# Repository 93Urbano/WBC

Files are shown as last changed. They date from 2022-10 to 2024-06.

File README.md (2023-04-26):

# WBC
WiFi-Bluetooth CAN-UART Datalogger ESP32
Currenly Desings:
- WBC_02 -> Wifi-Bluetooth-CAN board
  
- WBCR_02 -> Wifi-Bluetooth-CAN and Relays board

  


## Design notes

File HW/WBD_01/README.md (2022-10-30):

# WBC
WiFi-Bluetooth CAN-UART Datalogger ESP32

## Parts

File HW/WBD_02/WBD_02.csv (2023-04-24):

Qty | Value | Device | Package | Parts | Description | ARROW_PART_NUMBER | ARROW_PRICE-STOCK | DESCRIPTION | HEIGHT | MANUFACTURER_NAME | MANUFACTURER_PART_NUMBER | MOUSER_PART_NUMBER | MOUSER_PRICE-STOCK | MOUSER_TESTING_PART_NUMBER | MOUSER_TESTING_PRICE-STOCK | POPULARITY | SPICEPREFIX
2 |  | PINHD-1X2 | 1X02 | CAN, VBAT | PIN HEADER |  |  |  |  |  |  |  |  |  |  | 98
1 |  | PINHD-1X6 | 1X06 | UART/I2C | PIN HEADER |  |  |  |  |  |  |  |  |  |  | 79
6 | 0.1uF | C-EUC0603 | C0603 | C2, C3, C8, C9, C10, C11 | CAPACITOR, European symbol
1 | 100nF | C-EUC0603 | C0603 | C5 | CAPACITOR, European symbol
1 | 10k | R-EU_R0603 | R0603 | R1 | RESISTOR, European symbol |  |  |  |  |  |  |  |  |  |  | 70 | R
1 | 10uF | C-EUC0603 | C0603 | C6 | CAPACITOR, European symbol
1 | 13k | R-EU_R0603 | R0603 | R3 | RESISTOR, European symbol |  |  |  |  |  |  |  |  |  |  | 70 | R
3 | 150060GS75000 | 150060GS75000 | LEDC1608X80N | 3V3, LED, VIN | Wurth Elektronik WL-SMCW 520 nm Green LED, 1608 (0603) Clear SMD package |  |  | Wurth Elektronik WL-SMCW 520 nm Green LED, 1608 (0603) Clear SMD package | 0.8mm | Wurth Elektronik | 150060GS75000 | 710-150060GS75000 | https://www.mouser.co.uk/ProductDetail/Wurth-Elektronik/150060GS75000?qs=LlUlMxKIyB0UYkq5lDO8nA%3D%3D
1 | 1k | R-EU_R0603 | R0603 | R9 | RESISTOR, European symbol |  |  |  |  |  |  |  |  |  |  | 70 | R
1 | 20uF | C-EUC0603 | C0603 | C1 | CAPACITOR, European symbol
1 | 216990-0003 | 216990-0003 | 2169900003 | USBC | USB Connectors Mid-Mnt SMT CH0.58 16Ckt Type C Rec. |  |  | USB Connectors Mid-Mnt SMT CH0.58 16Ckt Type C Rec. | 3.36mm | Molex | 216990-0003 | 538-216990-0003 | https://www.mouser.co.uk/ProductDetail/Molex/216990-0003?qs=DRkmTr78QASn0GILUGAYCA%3D%3D
1 | 22pF | C-EUC0603 | C0603 | C4 | CAPACITOR, European symbol
1 | 22uF | C-EUC0603 | C0603 | C7 | CAPACITOR, European symbol
1 | 2k2 | R-EU_R0603 | R0603 | R8 | RESISTOR, European symbol |  |  |  |  |  |  |  |  |  |  | 70 | R
3 | 330 | R-EU_R0603 | R0603 | R4, R5, R10 | RESISTOR, European symbol |  |  |  |  |  |  |  |  |  |  | 70 | R
1 | 4.7uH | L-EUL5650M | L5650M | L1 | INDUCTOR, European symbol |  |  |  |  |  |  |  |  |  |  | 0 | L
1 | 40.2k | R-EU_R0603 | R0603 | R2 | RESISTOR, European symbol |  |  |  |  |  |  |  |  |  |  | 70 | R
2 | 5.1k | R-EU_R0603 | R0603 | R6, R7 | RESISTOR, European symbol |  |  |  |  |  |  |  |  |  |  | 70 | R
1 | 5V5 1F | DB-5R5D105T | CAPPRD500W130D2150H800 | SUPERCAPACITOR | Supercapacitors / Ultracapacitors MEM CAP 5.5V 1.0F |  |  | Supercapacitors / Ultracapacitors MEM CAP 5.5V 1.0F | 8mm | Elna | DB-5R5D105T | 555-DB-5R5D105T | https://www.mouser.co.uk/ProductDetail/Elna/DB-5R5D105T?qs=r8OyiFxb6Rcu1BWmqcONIQ%3D%3D
1 | AT24C32D-SSHM-B | AT24C32D-SSHM-B | SOIC127P600X175-8N | IC5 | AT24C32D-SSHM-B, EEPROM Memory 32kbit,, 4096 x, 8bit, Serial-2 Wire, 550ns 1.7 5.5 V, 8-Pin SOIC |  |  | AT24C32D-SSHM-B, EEPROM Memory 32kbit,, 4096 x, 8bit, Serial-2 Wire, 550ns 1.7 5.5 V, 8-Pin SOIC | 1.75mm | Microchip | AT24C32D-SSHM-B | 556-AT24C32D-SSHM-B | https://www.mouser.co.uk/ProductDetail/Microchip-Technology-Atmel/AT24C32D-SSHM-B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
1 | BAS85,115 | BAS85,115 | BAS85115 | D2 | Schottky Diodes & Rectifiers SCHOTTKY 30V 200MA |  |  | Schottky Diodes & Rectifiers SCHOTTKY 30V 200MA | 1.6mm | Nexperia | BAS85,115 | 771-BAS85-T/R | https://www.mouser.co.uk/ProductDetail/Nexperia/BAS85115?qs=me8TqzrmIYWCmVXtgUH2Gg%3D%3D
1 | DIO6970TST6 | DIO6970TST6 | SOT95P280X90-6N | IC2 | Switching Voltage Regulators 2A Step Converter 24V Input Sync |  |  | Switching Voltage Regulators 2A Step Converter 24V Input Sync | 0.9mm | DIOO Microcircuits | DIO6970TST6 | 453-DIO6970ST6 | https://www.mouser.co.uk/ProductDetail/DIOO-Microcircuits/DIO6970TST6?qs=%252BEew9%252B0nqrCWpKu8WqElxA%3D%3D
1 | DS05-127-2-04BK-SMT-TR | DS05-127-2-04BK-SMT-TR | DS05127204BKSMTTR | IC7 | DIP Switches / SIP Switches DIP Switch, SPST, 1.27 pitch, flat actuator, SMT, Tape and reel, 4 position, Black |  |  | DIP Switches / SIP Switches DIP Switch, SPST, 1.27 pitch, flat actuator, SMT, Tape and reel, 4 position, Black | 2.6mm | CUI Devices | DS05-127-2-04BK-SMT-TR | 490-DS05127204BK-STR | https://www.mouser.co.uk/ProductDetail/CUI-Devices/DS05-127-2-04BK-SMT-TR?qs=wnTfsH77Xs6LBykqEPH3sg%3D%3D
1 | DS3231M+TRL | DS3231M+TRL | SOIC127P1032X265-16N | IC4 | +/-5ppm, I2C Real-Time Clock |  |  | +/-5ppm, I2C Real-Time Clock | 2.65mm | Maxim Integrated | DS3231M+TRL | 700-DS3231M+TRL | https://www.mouser.co.uk/ProductDetail/Maxim-Integrated/DS3231M%2bTRL?qs=Bakm8ERcljq5PBzSwLfmgg%3D%3D
1 | ESP32-S3-WROOM-1-N16 | ESP32-S3-WROOM-1-N16 | ESP32S3WROOM1N16 | ESP32 | WiFi Modules - 802.11 [Engineering Samples] SMD Module, ESP32-S3, 16 MB SPI Flash, PCB Antenna |  |  | WiFi Modules - 802.11 [Engineering Samples] SMD Module, ESP32-S3, 16 MB SPI Flash, PCB Antenna | 3.25mm | Espressif Systems | ESP32-S3-WROOM-1-N16 | 356-ESP32S3WROOM1N16 | https://www.mouser.co.uk/ProductDetail/Espressif-Systems/ESP32-S3-WROOM-1-N16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
1 | MICROSD-PUSH-OUT | MICROSD-PUSH-OUT | MICROSD-PUSH-OUT | MICROSD | T-Flash Push-Out Micro SD Card Reader
1 | SN65HVD232D | SN65HVD232D | SOIC127P600X175-8N | IC3 | CAN Transceiver 1Mbit/s ISO 11898, 8-Pin SOIC |  |  | CAN Transceiver 1Mbit/s ISO 11898, 8-Pin SOIC | 1.75mm | Texas Instruments | SN65HVD232D | 595-SN65HVD232D | https://www.mouser.co.uk/ProductDetail/Texas-Instruments/SN65HVD232D?qs=QViXGNcIEAueLIS9b8IyYg%3D%3D
1 | SS34B-HF | SS34B-HF | DIOM5336X320N | D3 | Schottky Diodes & Rectifiers DIODE SCHOTTKY 3A 40V SMB |  |  | Schottky Diodes & Rectifiers DIODE SCHOTTKY 3A 40V SMB | 3.2mm | Comchip Technology | SS34B-HF | 750-SS34B-HF | https://www.mouser.co.uk/ProductDetail/Comchip-Technology/SS34B-HF?qs=vmHwEFxEFR9G1M%252BcUPG%2FxQ%3D%3D

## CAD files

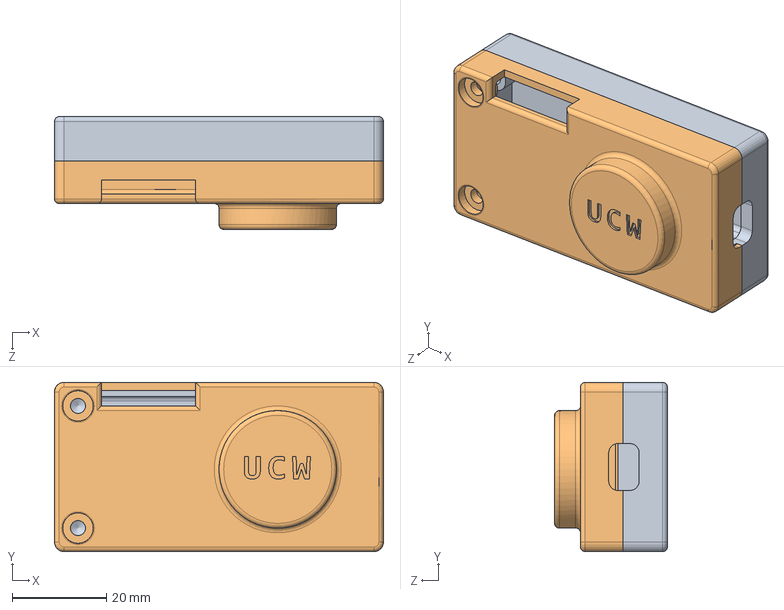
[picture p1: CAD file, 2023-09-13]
3Dcase/Ensamble.SLDASM
70.0 x 36.0 x 24.0 mm
Bottom
Top

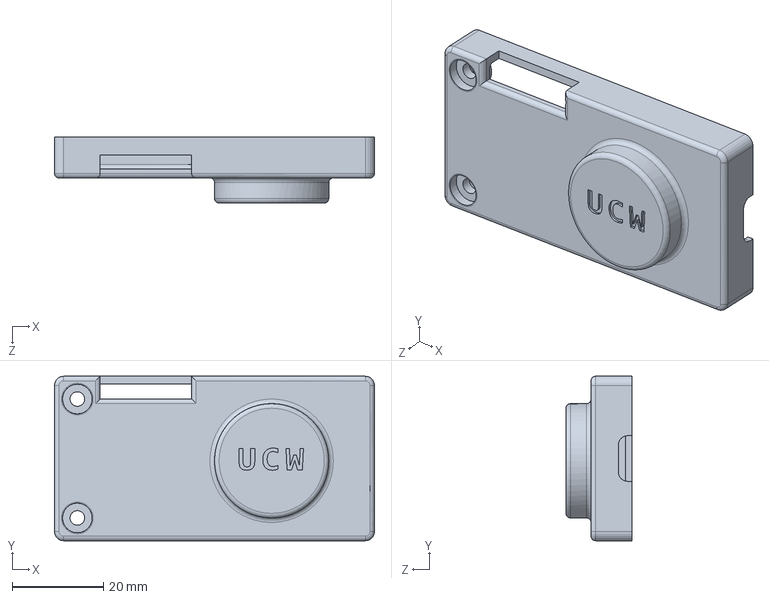
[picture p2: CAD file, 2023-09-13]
3Dcase/Bottom.SLDPRT
70.0 x 36.0 x 14.5 mm

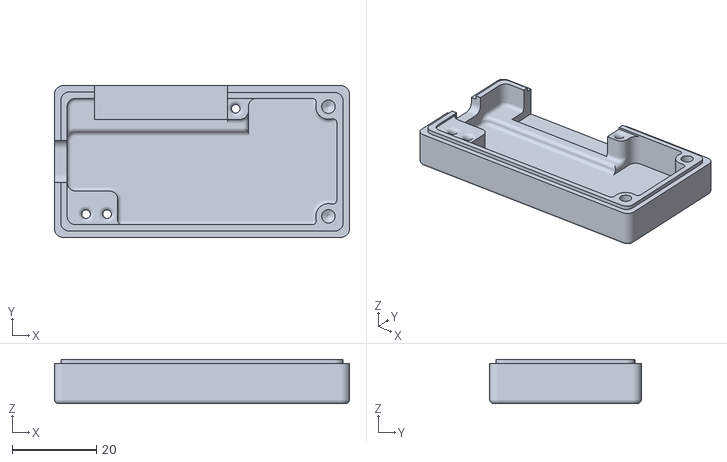
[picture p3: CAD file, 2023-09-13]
3Dcase/UCW_Top.STL
70.0 x 36.0 x 10.5

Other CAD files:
3Dcase/UCW_Bottom.STL
3Dcase/Top.SLDPRT

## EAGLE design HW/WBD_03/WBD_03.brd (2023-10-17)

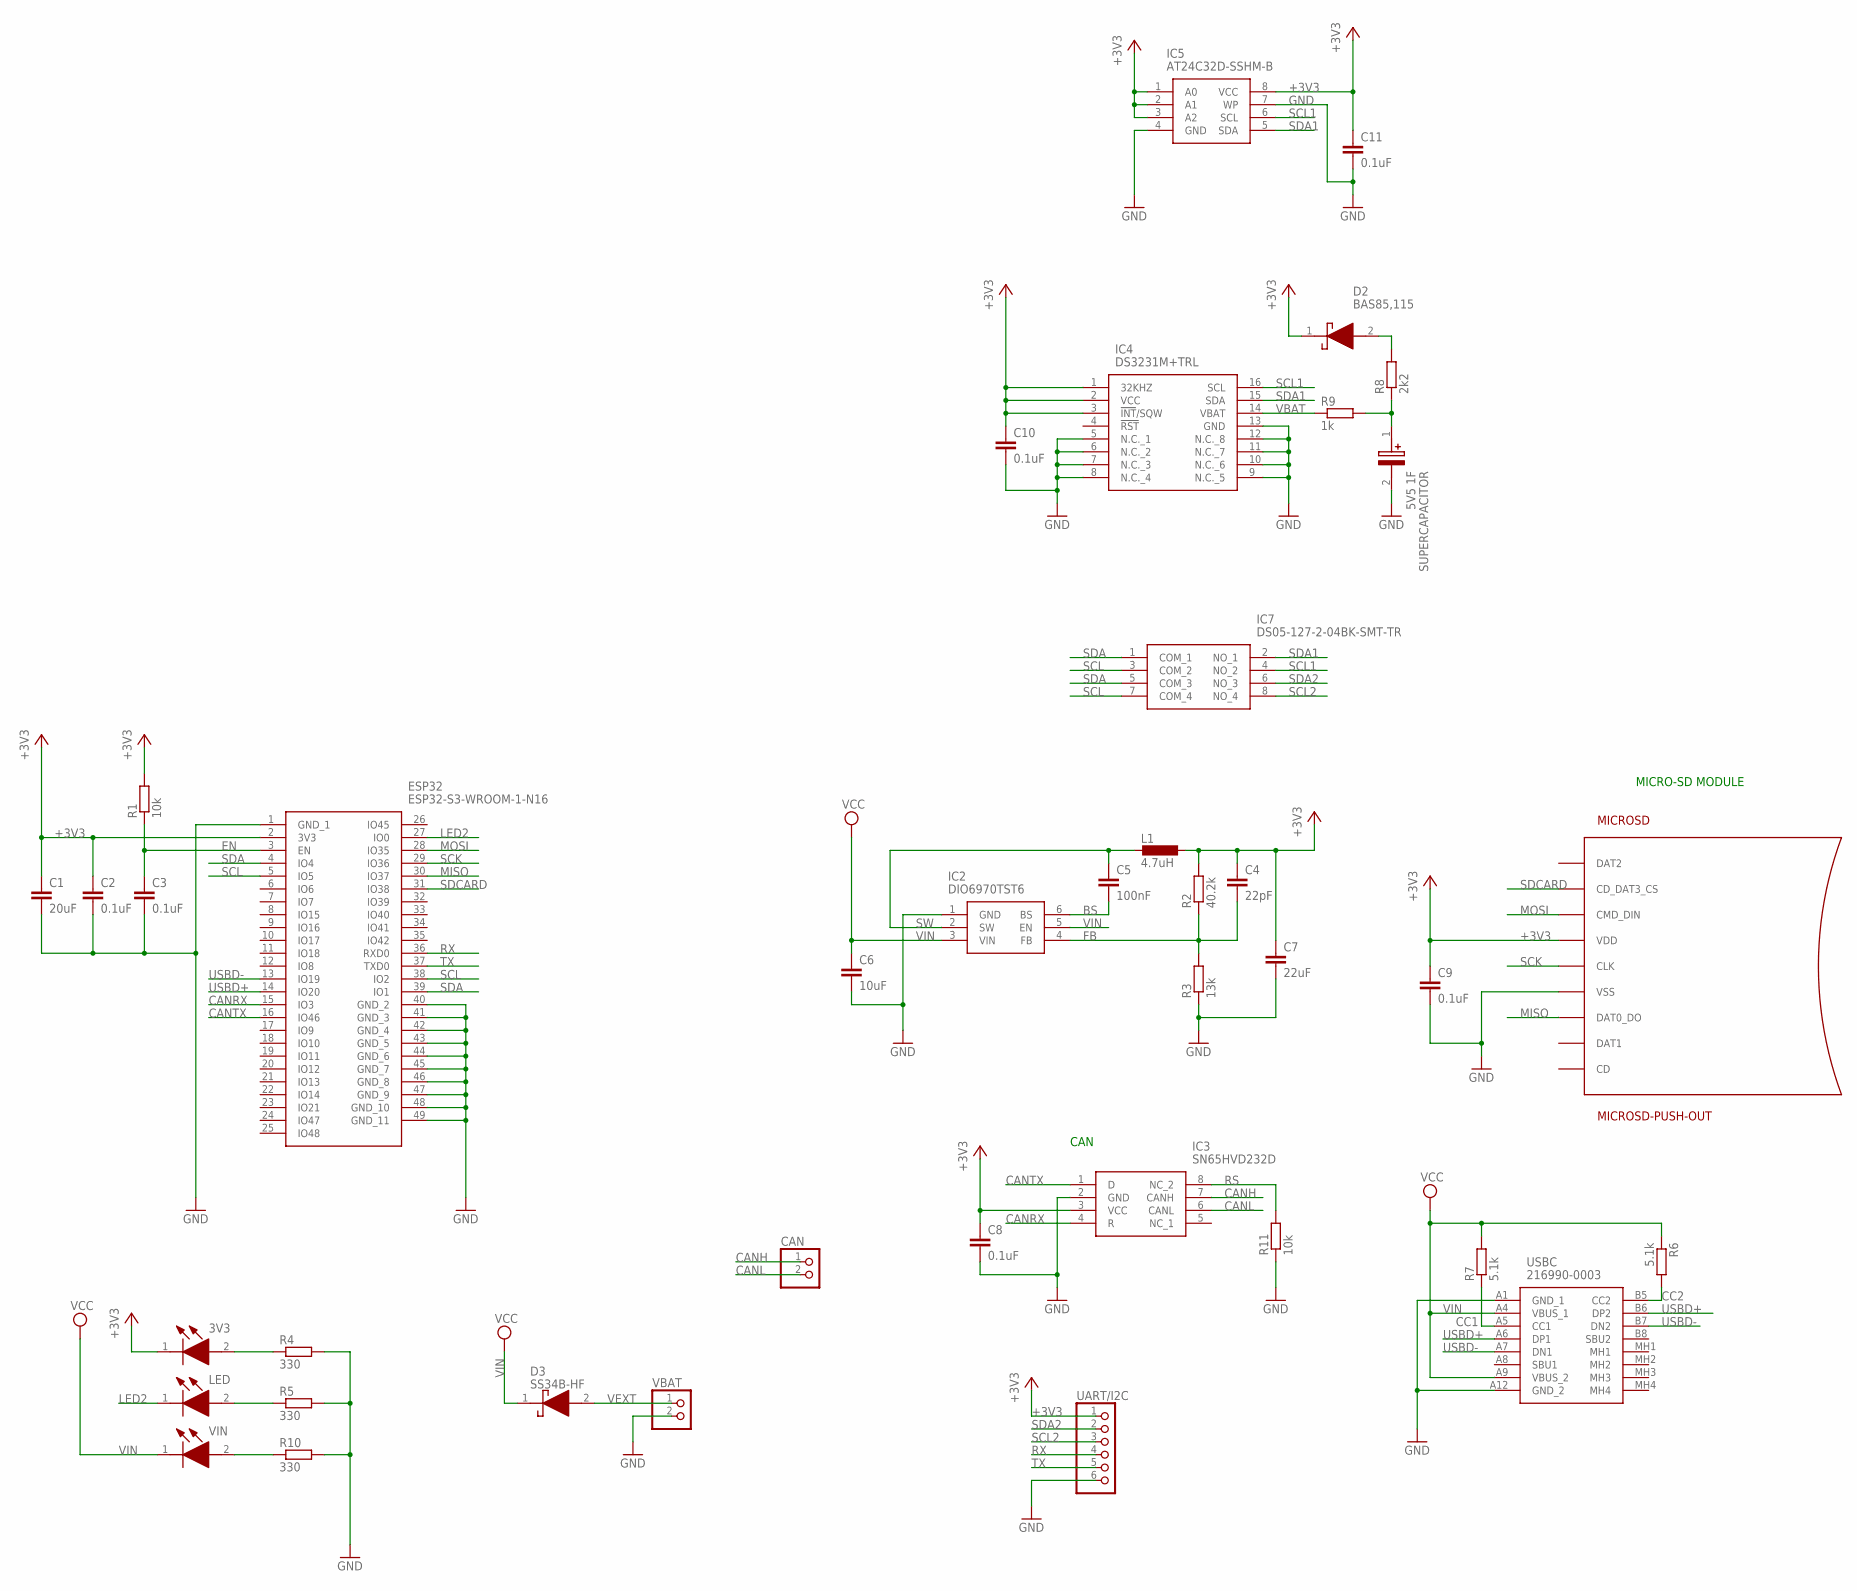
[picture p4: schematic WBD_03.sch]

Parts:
3V3: 150060GS75000; LEDC1608X80N
C1: 20uF; C0603
C2, C3, C8, C9, C10, C11: 0.1uF; C0603
C4: 22pF; C0603
C5: 100nF; C0603
C6: 10uF; C0603
C7: 22uF; C0603
CAN: PINHD-1X2; 1X02
D2: BAS85,115; BAS85115
D3: SS34B-HF; DIOM5336X320N
ESP32: ESP32-S3-WROOM-1-N16; ESP32S3WROOM1N16
IC2: DIO6970TST6; SOT95P280X90-6N
IC3: SN65HVD232D; SOIC127P600X175-8N
IC4: DS3231M+TRL; SOIC127P1032X265-16N
IC5: AT24C32D-SSHM-B; SOIC127P600X175-8N
IC7: DS05-127-2-04BK-SMT-TR; DS05127204BKSMTTR
L1: 4.7uH; L5650M
LED: 150060GS75000; LEDC1608X80N
MICROSD: MICROSD-PUSH-OUT
R1, R11: 10k; R0603
R2: 40.2k; R0603
R3: 13k; R0603
R4, R5, R10: 330; R0603
R6, R7: 5.1k; R0603
R8: 2k2; R0603
R9: 1k; R0603
SUPERCAPACITOR: 5V5 1F; CAPPRD500W130D2150H800
UART/I2C: PINHD-1X6; 1X06
USBC: 216990-0003; 2169900003
VBAT: PINHD-1X2; 1X02
VIN: 150060GS75000; LEDC1608X80N

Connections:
+3V3: 3V3.1 (K), C1.1, C2.1, C4.1, C7.1, C8.1, C9.1, C10.1, C11.1, D2.1 (K), ESP32.2 (3V3), IC3.3 (VCC), IC4.1 (32KHZ), IC4.2 (VCC), IC4.3 (!INT!/SQW), IC5.1 (A0), IC5.2 (A1), IC5.3 (A2), IC5.8 (VCC), L1.1, MICROSD.4 (VDD), R1.2, R2.2, UART/I2C.1
BS: C5.2, IC2.6 (BS)
CANH: CAN.1, IC3.7 (CANH)
CANL: CAN.2, IC3.6 (CANL)
CANRX: ESP32.15 (IO3), IC3.4 (R)
CANTX: ESP32.16 (IO46), IC3.1 (D)
CC1: R7.1, USBC.A5 (CC1)
CC2: R6.2, USBC.B5 (CC2)
EN: C3.1, ESP32.3 (EN), R1.1
FB: C4.2, IC2.4 (FB), R2.1, R3.2
GND: C1.2, C2.2, C3.2, C6.2, C7.2, C8.2, C9.2, C10.2, C11.2, ESP32.1 (GND_1), ESP32.40 (GND_2), ESP32.41 (GND_3), ESP32.42 (GND_4), ESP32.43 (GND_5), ESP32.44 (GND_6), ESP32.45 (GND_7), ESP32.46 (GND_8), ESP32.47 (GND_9), ESP32.48 (GND_10), ESP32.49 (GND_11), IC2.1 (GND), IC3.2 (GND), IC4.5 (N.C._1), IC4.6 (N.C._2), IC4.7 (N.C._3), IC4.8 (N.C._4), IC4.9 (N.C._5), IC4.10 (N.C._6), IC4.11 (N.C._7), IC4.12 (N.C._8), IC4.13 (GND), IC5.4 (GND), IC5.7 (WP), MICROSD.6 (VSS), MICROSD.G1 (VSS), MICROSD.G2 (VSS), MICROSD.G3 (VSS), MICROSD.G4 (VSS), R3.1, R4.2, R5.2, R10.2, R11.1, SUPERCAPACITOR.2 (-), UART/I2C.6, USBC.A1 (GND_1), USBC.A12 (GND_2), VBAT.2
LDR1: 3V3.2 (A), R4.1
LDR2: LED.2 (A), R5.1
LDR3: R10.1, VIN.2 (A)
LED2: ESP32.27 (IO0), LED.1 (K)
MISO: ESP32.30 (IO37), MICROSD.7 (DAT0_DO)
MOSI: ESP32.28 (IO35), MICROSD.3 (CMD_DIN)
RS: IC3.8 (NC_2), R11.2
RTCBAT: R8.1, R9.2, SUPERCAPACITOR.1 (+)
RTCD: D2.2 (A), R8.2
RX: ESP32.36 (RXD0), UART/I2C.4
SCK: ESP32.29 (IO36), MICROSD.5 (CLK)
SCL: ESP32.5 (IO5), ESP32.38 (IO2), IC7.3 (COM_2), IC7.7 (COM_4)
SCL1: IC4.16 (SCL), IC5.6 (SCL), IC7.4 (NO_2)
SCL2: IC7.8 (NO_4), UART/I2C.3
SDA: ESP32.4 (IO4), ESP32.39 (IO1), IC7.1 (COM_1), IC7.5 (COM_3)
SDA1: IC4.15 (SDA), IC5.5 (SDA), IC7.2 (NO_1)
SDA2: IC7.6 (NO_3), UART/I2C.2
SDCARD: ESP32.31 (IO38), MICROSD.2 (CD_DAT3_CS)
SW: C5.1, IC2.2 (SW), L1.2
TX: ESP32.37 (TXD0), UART/I2C.5
USBD+: ESP32.14 (IO20), USBC.A6 (DP1), USBC.B6 (DP2)
USBD-: ESP32.13 (IO19), USBC.A7 (DN1), USBC.B7 (DN2)
VBAT: IC4.14 (VBAT), R9.1
VEXT: D3.2 (A), VBAT.1
VIN: C6.1, D3.1 (K), IC2.3 (VIN), IC2.5 (EN), R6.1, R7.2, USBC.A4 (VBUS_1), USBC.A9 (VBUS_2), VIN.1 (K)

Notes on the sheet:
CAN
MICRO-SD MODULE

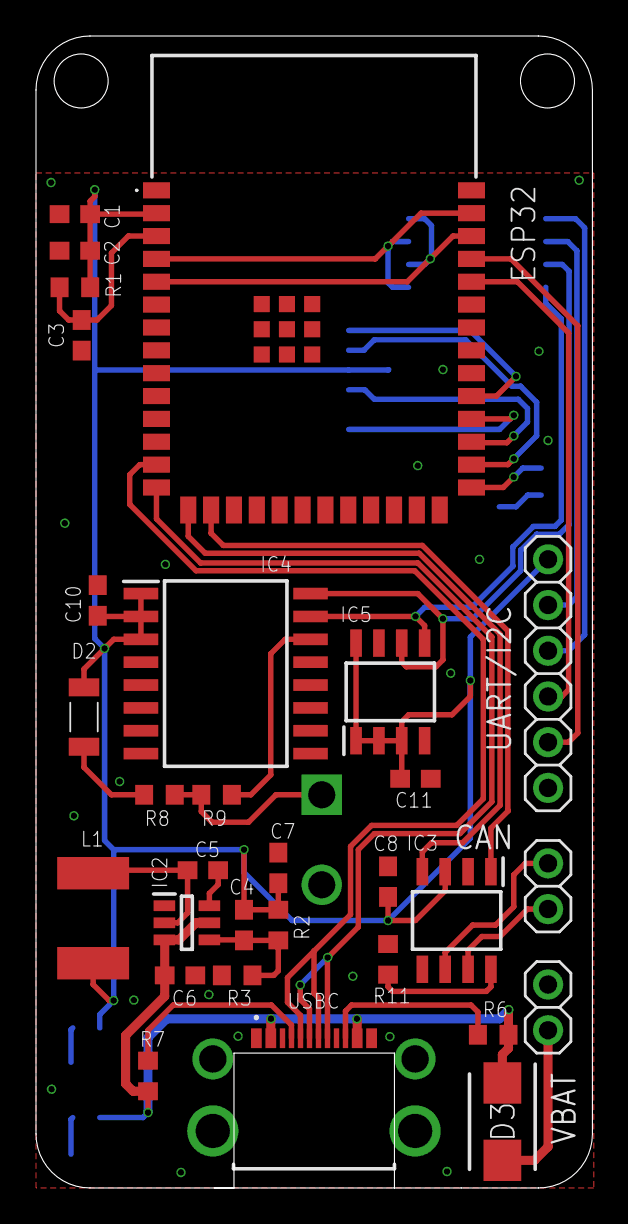
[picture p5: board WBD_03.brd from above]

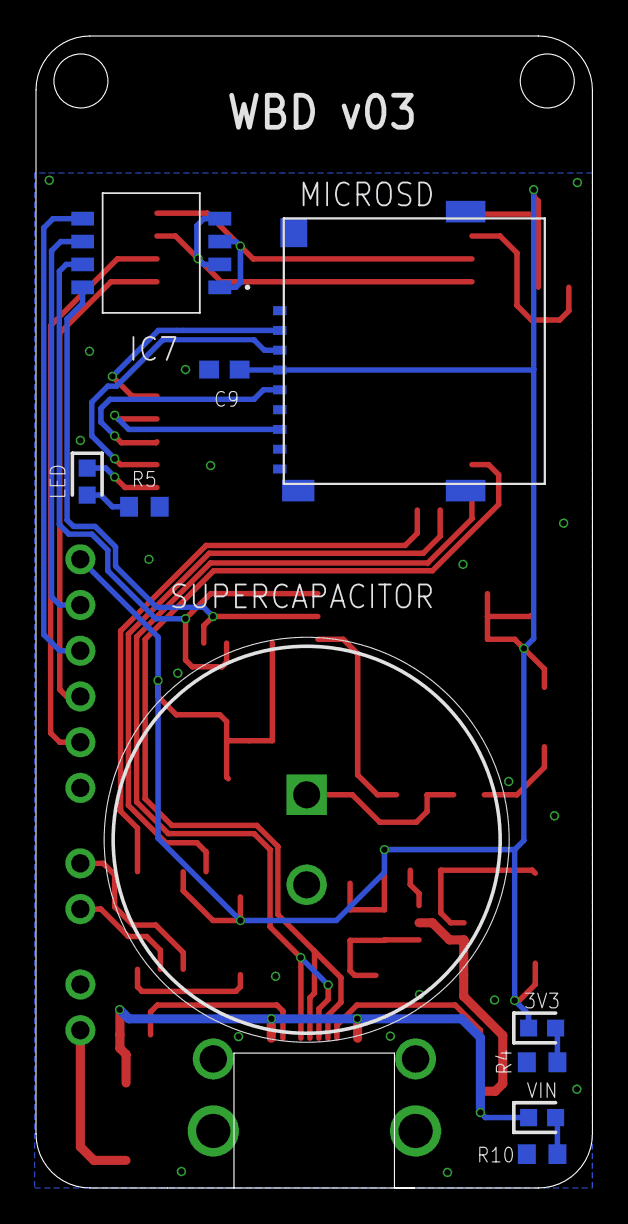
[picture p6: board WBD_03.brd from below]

Board: 2 copper layers, 30.9 x 64.0 mm, 40 parts (10 on the bottom side), 36 nets.

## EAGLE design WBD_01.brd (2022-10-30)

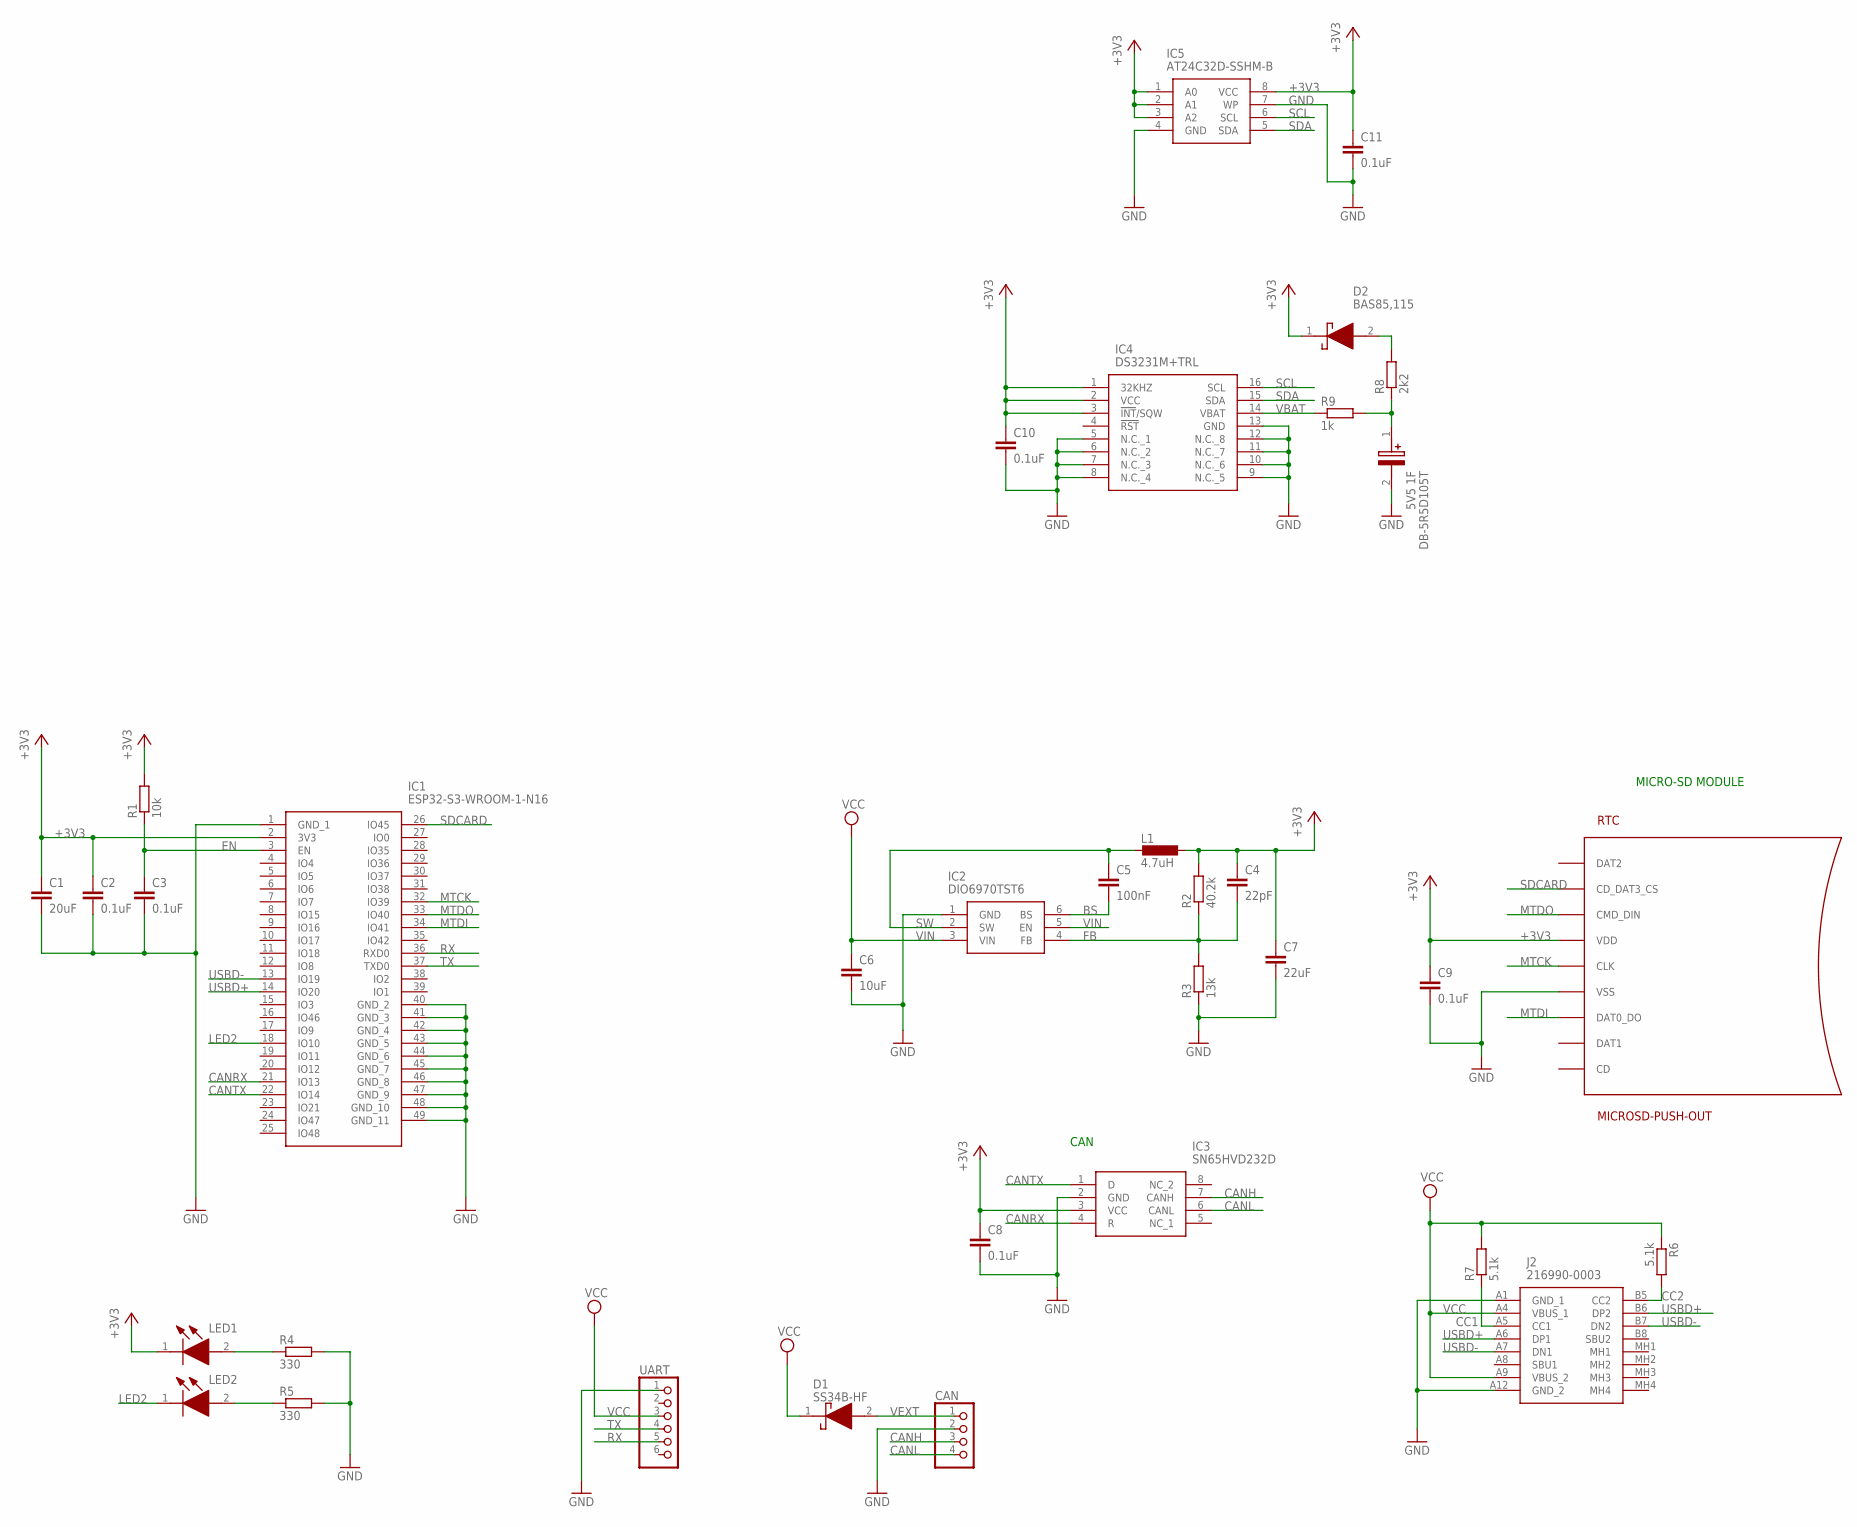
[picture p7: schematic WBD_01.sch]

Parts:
C1: 20uF; C0603
C2, C3, C8, C9, C10, C11: 0.1uF; C0603
C4: 22pF; C0603
C5: 100nF; C0603
C6: 10uF; C0603
C7: 22uF; C0603
CAN: PINHD-1X4M; 1X04M
D1: SS34B-HF; DIOM5336X320N
D2: BAS85,115; BAS85115
DB-5R5D105T: 5V5 1F; CAPPRD500W130D2150H800
IC1: ESP32-S3-WROOM-1-N16; ESP32S3WROOM1N16
IC2: DIO6970TST6; SOT95P280X90-6N
IC3: SN65HVD232D; SOIC127P600X175-8N
IC4: DS3231M+TRL; SOIC127P1032X265-16N
IC5: AT24C32D-SSHM-B; SOIC127P600X175-8N
J2: 216990-0003; 2169900003
L1: 4.7uH; L5650M
LED1, LED2: 150060GS75000; LEDC1608X80N
R1: 10k; R0603
R2: 40.2k; R0603
R3: 13k; R0603
R4, R5: 330; R0603
R6, R7: 5.1k; R0603
R8: 2k2; R0603
R9: 1k; R0603
RTC: MICROSD-PUSH-OUT
UART: PINHD-1X6M; 1X06M

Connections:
+3V3: C1.1, C2.1, C4.1, C7.1, C8.1, C9.1, C10.1, C11.1, D2.1 (K), IC1.2 (3V3), IC3.3 (VCC), IC4.1 (32KHZ), IC4.2 (VCC), IC4.3 (!INT!/SQW), IC5.1 (A0), IC5.2 (A1), IC5.3 (A2), IC5.8 (VCC), L1.1, LED1.1 (K), R1.2, R2.2, RTC.4 (VDD)
BS: C5.2, IC2.6 (BS)
CANH: CAN.3, IC3.7 (CANH)
CANL: CAN.4, IC3.6 (CANL)
CANRX: IC1.21 (IO13), IC3.4 (R)
CANTX: IC1.22 (IO14), IC3.1 (D)
CC1: J2.A5 (CC1), R7.1
CC2: J2.B5 (CC2), R6.2
EN: C3.1, IC1.3 (EN), R1.1
FB: C4.2, IC2.4 (FB), R2.1, R3.2
GND: C1.2, C2.2, C3.2, C6.2, C7.2, C8.2, C9.2, C10.2, C11.2, CAN.2, DB-5R5D105T.2 (-), IC1.1 (GND_1), IC1.40 (GND_2), IC1.41 (GND_3), IC1.42 (GND_4), IC1.43 (GND_5), IC1.44 (GND_6), IC1.45 (GND_7), IC1.46 (GND_8), IC1.47 (GND_9), IC1.48 (GND_10), IC1.49 (GND_11), IC2.1 (GND), IC3.2 (GND), IC4.5 (N.C._1), IC4.6 (N.C._2), IC4.7 (N.C._3), IC4.8 (N.C._4), IC4.9 (N.C._5), IC4.10 (N.C._6), IC4.11 (N.C._7), IC4.12 (N.C._8), IC4.13 (GND), IC5.4 (GND), IC5.7 (WP), J2.A1 (GND_1), J2.A12 (GND_2), R3.1, R4.2, R5.2, RTC.6 (VSS), RTC.G1 (VSS), RTC.G2 (VSS), RTC.G3 (VSS), RTC.G4 (VSS), UART.1
LDR1: LED1.2 (A), R4.1
LDR2: LED2.2 (A), R5.1
LED2: IC1.18 (IO10), LED2.1 (K)
MTCK: IC1.32 (IO39), RTC.5 (CLK)
MTDI: IC1.34 (IO41), RTC.7 (DAT0_DO)
MTDO: IC1.33 (IO40), RTC.3 (CMD_DIN)
RTCBAT: DB-5R5D105T.1 (+), R8.1, R9.2
RTCD: D2.2 (A), R8.2
RX: IC1.36 (RXD0), UART.5
SCL: IC4.16 (SCL), IC5.6 (SCL)
SDA: IC4.15 (SDA), IC5.5 (SDA)
SDCARD: IC1.26 (IO45), RTC.2 (CD_DAT3_CS)
SW: C5.1, IC2.2 (SW), L1.2
TX: IC1.37 (TXD0), UART.4
USBD+: IC1.14 (IO20), J2.A6 (DP1), J2.B6 (DP2)
USBD-: IC1.13 (IO19), J2.A7 (DN1), J2.B7 (DN2)
VBAT: IC4.14 (VBAT), R9.1
VCC: D1.1 (K), J2.A4 (VBUS_1), J2.A9 (VBUS_2), R6.1, R7.2, UART.3
VEXT: CAN.1, D1.2 (A)
VIN: C6.1, IC2.3 (VIN), IC2.5 (EN)

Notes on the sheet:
CAN
MICRO-SD MODULE

Board: 2 copper layers, 35 parts (2 on the bottom side), 31 nets, no tracks yet.

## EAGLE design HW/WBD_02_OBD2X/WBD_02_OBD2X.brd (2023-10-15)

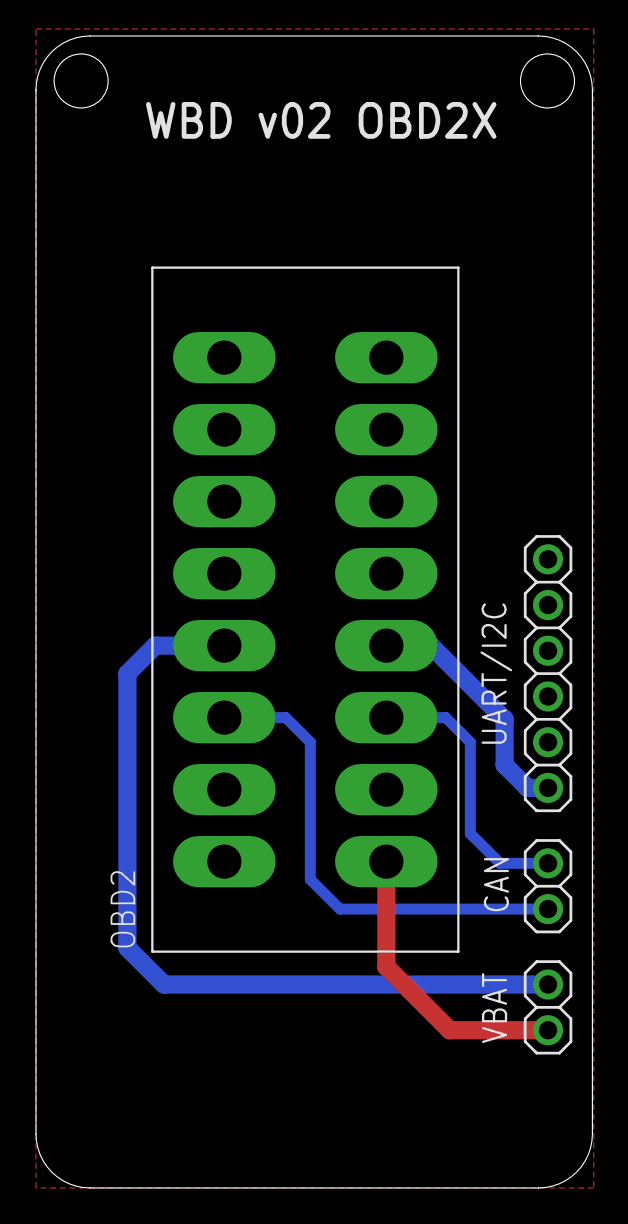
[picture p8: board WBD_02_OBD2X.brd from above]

Board: 2 copper layers, 30.9 x 64.0 mm, 4 parts (0 on the bottom side), 4 nets.

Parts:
CAN: 1X02
OBD2: OBD2
UART/I2C: 1X06
VBAT: 1X02

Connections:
CANH: CAN.1, OBD2.6
CANL: CAN.2, OBD2.14
GND: OBD2.5, OBD2.13, UART/I2C.6, VBAT.2
VEXT: OBD2.16, VBAT.1

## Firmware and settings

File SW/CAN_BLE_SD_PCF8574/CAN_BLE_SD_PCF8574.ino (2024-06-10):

// Date and time functions using a DS3231 RTC connected via I2C and Wire lib
#include "RTClib.h"

RTC_DS3231 rtc;

char daysOfTheWeek[7][12] = {"Sunday", "Monday", "Tuesday", "Wednesday", "Thursday", "Friday", "Saturday"};
#define I2C_SDA 1
#define I2C_SCL 2

//PCF8574
const int pcfAddress = 0x27;
//#include <Wire.h>


String DateNameFileString;

//SD
#include "FS.h"
#include "SD.h"
#include "SPI.h"

#define SCK  36
#define MISO  37
#define MOSI  35
#define CS  38

SPIClass spi = SPIClass(HSPI);

//CAN
#include "driver/gpio.h"
#include "driver/twai.h"

//concatenacion de cadenas
#include <iostream>
#include <cstdio>  

//BLE
#include <BLEDevice.h>
#include <BLEServer.h>
#include <BLEUtils.h>
#include <BLE2902.h>
BLEServer *pServer = NULL;
BLECharacteristic * pTxCharacteristic;
bool deviceConnected = false;
bool oldDeviceConnected = false;
uint8_t txValue = 0;
unsigned char LED=0;
bool ledState=0;
char Str1[20];
// See the following for generating UUIDs:
// https://www.uuidgenerator.net/
#define SERVICE_UUID           "6E400001-B5A3-F393-E0A9-E50E24DCCA9E" // UART service UUID
#define CHARACTERISTIC_UUID_RX "6E400002-B5A3-F393-E0A9-E50E24DCCA9E"
#define CHARACTERISTIC_UUID_TX "6E400003-B5A3-F393-E0A9-E50E24DCCA9E"
char buffer[100];

//BLE
class MyServerCallbacks: public BLEServerCallbacks 
{
    void onConnect(BLEServer* pServer) 
    {
        deviceConnected = true;
    };

    void onDisconnect(BLEServer* pServer) 
    {
        deviceConnected = false;
    }
};

class MyCallbacks: public BLECharacteristicCallbacks 
{
    void onWrite(BLECharacteristic *pCharacteristic) 
    {
        std::string rxValue = pCharacteristic->getValue();

        if (rxValue.length() > 0) 
        {
            Serial.println("*********");
            Serial.print("Received Value: ");
            for (int i = 0; i < rxValue.length(); i++)
                Serial.print(rxValue[i]);
            Serial.println();
            Serial.println("*********");
        }
    }
};

void WriteString2BLE(char *s)
{
  if (deviceConnected)
  {
    pTxCharacteristic->setValue(s);
    pTxCharacteristic->notify();
  }
}

void CANInit()
{
    //CAN
    twai_general_config_t g_config = TWAI_GENERAL_CONFIG_DEFAULT(GPIO_NUM_46, GPIO_NUM_3, TWAI_MODE_NORMAL);
    twai_timing_config_t t_config = TWAI_TIMING_CONFIG_100KBITS();
    twai_filter_config_t f_config = TWAI_FILTER_CONFIG_ACCEPT_ALL();
    //Install TWAI driver
    if (twai_driver_install(&g_config, &t_config, &f_config) == ESP_OK) 
    {
        printf("Driver installed\n");
    } 
    else 
    {
        printf("Failed to install driver\n");
        return;
    }
    //Start TWAI driver
    if (twai_start() == ESP_OK) 
    {
        printf("Driver started\n");
    } 
    else 
    {
        printf("Failed to start driver\n");
        return;
    }
}

void BLEInit()
{
    // BLE
    BLEDevice::init("UART Service");
    // Create the BLE Server
    pServer = BLEDevice::createServer();
    pServer->setCallbacks(new MyServerCallbacks());
    // Create the BLE Service
    BLEService *pService = pServer->createService(SERVICE_UUID);
    // Create a BLE Characteristic
    pTxCharacteristic = pService->createCharacteristic(
                        CHARACTERISTIC_UUID_TX,
                        BLECharacteristic::PROPERTY_NOTIFY
                        );
    pTxCharacteristic->addDescriptor(new BLE2902());
    BLECharacteristic * pRxCharacteristic = pService->createCharacteristic(
                                            CHARACTERISTIC_UUID_RX,
                                            BLECharacteristic::PROPERTY_WRITE
                                            );
    pRxCharacteristic->setCallbacks(new MyCallbacks());
    // Start the service
    pService->start();
    // Start advertising
    pServer->getAdvertising()->start();
    Serial.println("Waiting a client connection to notify...");
    pTxCharacteristic->setValue("Hello World");
}

void RTCInit()
{
  Wire.begin(I2C_SDA, I2C_SCL);
  #ifndef ESP8266
    while (!Serial); // wait for serial port to connect. Needed for native USB
  #endif

  if (! rtc.begin()) {
    Serial.println("Couldn't find RTC");
    Serial.flush();
    while (1) delay(10);
  }

  if (rtc.lostPower()) {
    Serial.println("RTC lost power, let's set the time!");
    // When time needs to be set on a new device, or after a power loss, the
    // following line sets the RTC to the date & time this sketch was compiled
    rtc.adjust(DateTime(F(__DATE__), F(__TIME__)));
    // This line sets the RTC with an explicit date & time, for example to set
    // January 21, 2014 at 3am you would call:
    // rtc.adjust(DateTime(2014, 1, 21, 3, 0, 0));
  }
}

void listDir(fs::FS &fs, const char * dirname, uint8_t levels){
  Serial.printf("Listing directory: %s\n", dirname);

  File root = fs.open(dirname);
  if(!root){
    Serial.println("Failed to open directory");
    return;
  }
  if(!root.isDirectory()){
    Serial.println("Not a directory");
    return;
  }

  File file = root.openNextFile();
  while(file){
    if(file.isDirectory()){
      Serial.print("  DIR : ");
      Serial.println(file.name());
      if(levels){
        listDir(fs, file.name(), levels -1);
      }
    } else {
      Serial.print("  FILE: ");
      Serial.print(file.name());
      Serial.print("  SIZE: ");
      Serial.println(file.size());
    }
    file = root.openNextFile();
  }
}

void createDir(fs::FS &fs, const char * path){
  Serial.printf("Creating Dir: %s\n", path);
  if(fs.mkdir(path)){
    Serial.println("Dir created");
  } else {
    Serial.println("mkdir failed");
  }
}

void removeDir(fs::FS &fs, const char * path){
  Serial.printf("Removing Dir: %s\n", path);
  if(fs.rmdir(path)){
    Serial.println("Dir removed");
  } else {
    Serial.println("rmdir failed");
  }
}

void readFile(fs::FS &fs, const char * path){
  Serial.printf("Reading file: %s\n", path);

  File file = fs.open(path);
  if(!file){
    Serial.println("Failed to open file for reading");
    return;
  }

  Serial.print("Read from file: ");
  while(file.available()){
    Serial.write(file.read());
  }
  file.close();
}

void writeFile(fs::FS &fs, const char * path, const char * message){
  Serial.printf("Writing file: %s\n", path);

  File file = fs.open(path, FILE_WRITE);
  if(!file){
    Serial.println("Failed to open file for writing");
    return;
  }
  if(file.print(message)){
    Serial.println("File written");
  } else {
    Serial.println("Write failed");
  }
  file.close();
}

void appendFile(fs::FS &fs, const char * path, const char * message){
  Serial.printf("Appending to file: %s\n", path);

  File file = fs.open(path, FILE_APPEND);
  if(!file){
    Serial.println("Failed to open file for appending");
    return;
  }
  if(file.print(message)){
    Serial.println("Message appended");
  } else {
    Serial.println("Append failed");
  }
  file.close();
}

void renameFile(fs::FS &fs, const char * path1, const char * path2){
  Serial.printf("Renaming file %s to %s\n", path1, path2);
  if (fs.rename(path1, path2)) {
    Serial.println("File renamed");
  } else {
    Serial.println("Rename failed");
  }
}

void deleteFile(fs::FS &fs, const char * path){
  Serial.printf("Deleting file: %s\n", path);
  if(fs.remove(path)){
    Serial.println("File deleted");
  } else {
    Serial.println("Delete failed");
  }
}

void testFileIO(fs::FS &fs, const char * path){
  File file = fs.open(path);
  static uint8_t buf[512];
  size_t len = 0;
  uint32_t start = millis();
  uint32_t end = start;
  if(file){
    len = file.size();
    size_t flen = len;
    start = millis();
    while(len){
      size_t toRead = len;
      if(toRead > 512){
        toRead = 512;
      }
      file.read(buf, toRead);
      len -= toRead;
    }
    end = millis() - start;
    Serial.printf("%u bytes read for %u ms\n", flen, end);
    file.close();
  } else {
    Serial.println("Failed to open file for reading");
  }


  file = fs.open(path, FILE_WRITE);
  if(!file){
    Serial.println("Failed to open file for writing");
    return;
  }

  size_t i;
  start = millis();
  for(i=0; i<2048; i++){
    file.write(buf, 512);
  }
  end = millis() - start;
  Serial.printf("%u bytes written for %u ms\n", 2048 * 512, end);
  file.close();
}

void SDInit()
{
  spi.begin(SCK, MISO, MOSI, CS);
  Serial.println("SD SETUP");

  if (!SD.begin(CS,spi,80000000)) {
    Serial.println("Card Mount Failed");
    return;
  }
  uint8_t cardType = SD.cardType();

  if(cardType == CARD_NONE){
    Serial.println("No SD card attached");
    return;
  }

  Serial.print("SD Card Type: ");
  if(cardType == CARD_MMC){
    Serial.println("MMC");
  } else if(cardType == CARD_SD){
    Serial.println("SDSC");
  } else if(cardType == CARD_SDHC){
    Serial.println("SDHC");
  } else {
    Serial.println("UNKNOWN");
  }

  uint64_t cardSize = SD.cardSize() / (1024 * 1024);
  Serial.printf("SD Card Size: %lluMB\n", cardSize);
  listDir(SD, "/", 0);
}

uint8_t PCF8574()
{
  short channel = 1;
  static byte PCF8574value = 0;

  DateNameFileString = GetDateFileName();
  const char* DateNameFile = DateNameFileString.c_str();
  String Timeget = GetTimeString();
  std::sprintf(buffer, "%s PCF8574 %X ", Timeget.c_str(), PCF8574value);
  std::string formattedString(buffer);
  const char* cString = formattedString.c_str();
  WriteString2BLE(const_cast<char*>(cString));
  appendFile(SD, DateNameFile, const_cast<char*>(cString));
  WriteString2BLE("\n");
  appendFile(SD, DateNameFile, "\n");
  // Mostrar el valor por puerto serie
  Serial.print("Valor PCF8574: ");
  Serial.println(PCF8574value);

  // Leer dato de canal 'channel'
  Wire.requestFrom(pcfAddress, 1 << channel);
  if (Wire.available())
  {
    PCF8574value = Wire.read();
    // Mostrar el valor por puerto serie
    Serial.print("Valor PCF8574: ");
    Serial.println(PCF8574value);
  }
  Wire.endTransmission();
  //Serial.println("1");
  return PCF8574value;
}

String GetTimeString ()
{
  DateTime now = rtc.now(); // Obtiene la fecha y hora actual del módulo RTC
  
  // Construye un string con el formato "HH:MM:SS"
  String hora = String(now.hour());
  String minutos = String(now.minute());
  String segundos = String(now.second());

  // Asegura que la hora, minutos y segundos tengan dos dígitos
  if (hora.length() == 1) hora = '0' + hora;
  if (minutos.length() == 1) minutos = '0' + minutos;
  if (segundos.length() == 1) segundos = '0' + segundos;

  return hora + ":" + minutos + ":" + segundos;
}

String GetDateFileName() 
{
  DateTime now = rtc.now(); // Obtiene la fecha y hora actual del módulo RTC

  // Construye un string con el formato "YYMMDDHH"
  String dia = String(now.day());
  String mes = String(now.month());
  String ano = String(now.year() - 2000); // Restamos 2000 ya que el año se almacena como los últimos dos dígitos
  String hora = String(now.hour());

  // Asegura que el día, mes, año, hora, minutos y segundos tengan dos dígitos
  if (dia.length() == 1) dia = '0' + dia;
  if (mes.length() == 1) mes = '0' + mes;
  if (ano.length() == 1) ano = '0' + ano;
  if (hora.length() == 1) hora = '0' + hora;

  return "/" + ano + mes + dia + hora + ".txt";
}


void setup()
{
    //CAN
    CANInit();
    //SERIAL
    Serial.begin(115200);
    //LED
    pinMode(LED, OUTPUT);
    //BLE
    BLEInit();
    //SD
    SDInit();
    //RTC
    RTCInit();
}

void loop ()
{
  static uint8_t PCF874byte;
  PCF874byte = PCF8574();
  DateNameFileString = GetDateFileName();
  //Serial.println("2");
  const char* DateNameFile = DateNameFileString.c_str();
  //Wait for message to be received
  twai_message_t message;
  //Serial.println("3");
  if (twai_receive(&message, pdMS_TO_TICKS(100)) == ESP_OK) 
  {
    //Serial.println("4");
    WriteString2BLE("\n");
    appendFile(SD, DateNameFile, "\n");
    if (!(message.rtr) && (message.identifier = 0x005)) 
    {
      String Timeget = GetTimeString();
      std::sprintf(buffer, "%s 0x%X ", Timeget.c_str(), message.identifier);
      std::string formattedString(buffer);
      const char* cString = formattedString.c_str();
      WriteString2BLE(const_cast<char*>(cString));
      appendFile(SD, DateNameFile, const_cast<char*>(cString));
      for (int i = 0; i < message.data_length_code; i++) 
      {
          std::sprintf(buffer, "%X ", message.data[i]);
          std::string formattedString(buffer);
          const char* cString = formattedString.c_str();
          WriteString2BLE(const_cast<char*>(cString));
          appendFile(SD, DateNameFile, const_cast<char*>(cString));
      }
      digitalWrite(LED, 1);
      if (message.data[1] != PCF874byte)
      {
        WriteString2BLE("MISSMATCH FAULT\n");
        appendFile(SD, DateNameFile, "MISSMATCH FAULT\n"); 
        Serial.print("MISSMATCH FAULT");
      }
    }
  }
  //Serial.println("5");
  // disconnecting
  if (!deviceConnected && oldDeviceConnected) 
  {
      pServer->startAdvertising(); // restart advertising
      Serial.println("start advertising");
      oldDeviceConnected = deviceConnected;
      digitalWrite(LED, 0);
      //Serial.println("6");
  }
  //Serial.println("7");
  // connecting
  if (deviceConnected && !oldDeviceConnected) 
  {
      //Serial.println("8");
      // do stuff here on connecting
      oldDeviceConnected = deviceConnected;
  }
}

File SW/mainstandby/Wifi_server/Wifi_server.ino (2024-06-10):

#include <WiFi.h>
#include <ESPAsyncWebServer.h>

const char* ssid     = "Galaxy S20+b24a";
const char* password = "davidjimenez";

AsyncWebServer server(80);

int rpmValue = 0;
int tpsPercentage = 0;
int brakePercentage = 0;
int ClutchState = 0;
int ledPin = 0;
uint CANfrequency = 1000000;
bool CANactive = 0;
uint UARTBauds = 115200;
bool UARTactive = 0;
bool CANShow = 0;
bool UARTShow = 0;
bool RTCShow = 0;
bool CANSave = 0;
bool UARTSave = 0;
bool RTCSave = 0;

void setup() {
  Serial.begin(115200);
  pinMode(ledPin, OUTPUT);
  digitalWrite(ledPin, LOW);

  WiFi.begin(ssid, password);

  while (WiFi.status() != WL_CONNECTED) {
    delay(1000);
    Serial.println("Connecting to WiFi...");
  }

  server.on("/", HTTP_GET, handleRoot);
  server.on("/data", HTTP_GET, handleData);
  server.on("/control", HTTP_POST, handleControl);
  server.on("/cancontrol", HTTP_POST, handleCANControl);
  server.on("/uartcontrol", HTTP_POST, handleUARTControl);
  server.on("/btconfig", HTTP_POST, handleBTControl);
  server.on("/dataconfig", HTTP_POST, handleDATAControl);
  server.on("/datetimeconfig", HTTP_POST, handleDATETIME);
  server.on("/Data Log", HTTP_GET, handleDataLog);
  server.on("/Configuration", HTTP_GET, handleConfig);

  server.begin();
}

void loop() {
  delay(1000);
  rpmValue += 100;
  tpsPercentage += 5;
  brakePercentage += 5;
  ClutchState +=1;
}

void handleRoot(AsyncWebServerRequest *request) {
  String html = "<html><head><title>ESP32 WBC</title></head><body>";
  html += "<h1>ESP32 WBC</h1>";
  html += "<ul>";
  html += "<li><a href='/Configuration'>Configuration</a></li>";
  html += "<li><a href='/Data Log'>Data Log</a></li>";
  html += "</ul>";
  html += "</body></html>";
  request->send(200, "text/html", html);
}

void handleDataLog(AsyncWebServerRequest *request) {
  String html = "<html><head><title>WBC Datalogger</title></head><body>";
  html += "<h1>ESP32 WBC - Datalogger</h1>";
  html += "<form id='controlForm'>";
  html += "<label for='ledControl'>LED Control:</label>";
  html += "<select id='ledControl' name='ledControl'>";
  html += "<option value='on'>LED ON</option>";
  html += "<option value='off'>LED OFF</option>";
  html += "</select>";
  html += "<br><br>";
  html += "<button type='button' onclick='sendLEDCommand()'>Send LED command</button>";
  html += "</form>";
  html += "<p>RPM: <span id='rpmValue'>" + String(rpmValue) + "</span></p>";
  html += "<p>%TPS: <span id='tpsValue'>" + String(tpsPercentage) + "</span></p>";
  html += "<p>%Brake: <span id='brakeValue'>" + String(brakePercentage) + "</span></p>";
  html += "<p>Clutch Status: <span id='ClutchValue'>" + String(ClutchState) + "</span></p>";
  html += "<script>";
  html += "function updateData() {";
  html += "  var rpmSpan = document.getElementById('rpmValue');";
  html += "  var tpsSpan = document.getElementById('tpsValue');";
  html += "  var brakeSpan = document.getElementById('brakeValue');";
  html += "  var clutchSpan = document.getElementById('ClutchValue');";
  html += "  var xhttp = new XMLHttpRequest();";
  html += "  xhttp.onreadystatechange = function() {";
  html += "    if (this.readyState == 4 && this.status == 200) {";
  html += "      var data = this.responseText.split(';');";
  html += "      rpmSpan.innerHTML = data[0];";
  html += "      tpsSpan.innerHTML = data[1];";
  html += "      brakeSpan.innerHTML = data[2];";
  html += "      clutchSpan.innerHTML = data[3];";
  html += "    }";
  html += "  };";
  html += "  xhttp.open('GET', '/data', true);";
  html += "  xhttp.send();";
  html += "}";
  html += "function sendLEDCommand() {";
  html += "  var ledControl = document.getElementById('ledControl').value;";
  html += "  var xhttp = new XMLHttpRequest();";
  html += "  xhttp.open('POST', '/control', true);";
  html += "  xhttp.setRequestHeader('Content-type', 'application/x-www-form-urlencoded');";
  html += "  xhttp.send('ledControl=' + ledControl);";
  html += "}";
  html += "setInterval(updateData, 1000);";
  html += "</script>";
  html += "</body></html>";
  request->send(200, "text/html", html);
}

void handleConfig(AsyncWebServerRequest *request) {
  String html = "<html><head><title>WBC Configuration</title></head><body>";
  html += "<h1>ESP32 WBC - Configuration</h1>";
  html += "<p><strong>CAN configuration:</strong></p>";
  html += "<form id=\"canFrequencyForm\">";
  html += "<label for=\"canFrequencyControl\">CAN Frequency:</label>";
  html += "<select id=\"canFrequencyControl\" name=\"canFrequencyControl\">";
  html += "<option value=\'1M'>1Mbit/s</option>";
  html += "<option value=\'100K'>100Kbit/s</option>";
  html += "</select>";
  html += "<p><label><input id=\"enableCAN\" name=\"canOption\" type=\"radio\" value=\'enable' onclick=\"toggleRadio('enableCAN', 'disableCAN')\" /> Enable CAN </label></p>";
  html += "<p><label><input id=\"disableCAN\" name=\"canOption\" type=\"radio\" value=\'disable' onclick=\"toggleRadio('disableCAN', 'enableCAN')\" /> Disable CAN </label></p>";
  html += "<p><button type='button' onclick='SendCANconfig()'>Send CAN config</button>";
  html += "</form>";

  html += "<form>";
  html += "<p><strong>UART configuration:</strong></p>";
  html += "<form id=\"uartBaudsForm\">";
  html += "<label for=\"uartBaudsControl\">UART Bauds:</label>";
  html += "<select id=\"uartBaudsControl\" name=\"uartBaudsControl\">";
  html += "<option value=\"9600\">9600</option>";
  html += "<option value=\"19200\">19200</option>";
  html += "<option value=\"38400\">38400</option>";
  html += "<option value=\"57600\">57600</option>";
  html += "<option value=\"115200\">115200</option>";
  html += "</select>";
  html += "<p><label><input id=\"enableUART\" name=\"uartOption\" type=\"radio\" value=\'enable' onclick=\"toggleRadio('enableUART', 'disableUART')\" /> Enable UART </label></p>";
  html += "<p><label><input id=\"disableUART\" name=\"uartOption\" type=\"radio\" value=\'disable' onclick=\"toggleRadio('disableUART', 'enableUART')\" /> Disable UART </label></p>";
  html += "<p><button type='button' onclick='SendUARTconfig()'>Send UART config</button>";
  html += "</form>";

  html += "<p><strong>BT configuration:</strong></p>";
  html += "<p><label><input name=\"showCAN\" type=\"radio\" value=\'yes' /> Show CAN </label></p>";
  html += "<p><label><input name=\"showUART\" type=\"radio\" value=\'yes' /> Show UART </label></p>";
  html += "<p><label><input name=\"showRTC\" type=\"radio\" value=\'yes' /> Show RTC </label></p>";
  html += "<p><button type='button' onclick='SendBTconfig()'>Send BT config</button>";
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

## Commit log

2022-11-08 WBD board
    [WBD_01.brd, WBD_01.sch, WBD_01dgj.brd]
2023-02-20 Change CAN and add new board WBDR
    [WBDR_02.brd, WBDR_02.sch, WBD_02.brd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]
2023-04-24 HW finished
    [WBDR_02.brd, WBDR_02.csv, WBDR_02.sch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]
2023-09-13 Cambios Overall
    [Bottom.SLDPRT, Ensamble.SLDASM, Top.SLDPRT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]
2023-09-16 Codigo general y expansion OBD2
    [WBD_02_OBD2X.brd]
2023-10-15 WBC_02_OBD2X Gerbers
    [WBD_02_OBD2X.brd]
2023-10-17 New WBD_03
    [WBD_03.brd, WBD_03.sch]
2023-10-17 Finish WBD_03 + gerbers
    [WBD_03.brd]
2023-12-31 Captura de CAN freq fixed
    [Wifi_server.ino]
